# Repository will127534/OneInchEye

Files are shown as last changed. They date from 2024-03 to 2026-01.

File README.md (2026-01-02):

# OneInchEye: OpenSource IMX283 Camera Board for Raspberry Pi


### Update on 2024/03/24
This project is also compatiable with RPI5, the quickstart guide has been updated.  

## Introduction
Welcome to the **OneInchEye** project, an open-source camera board designed for Raspberry Pi Compute Module 4 boards using the IMX283 one-inch sensor. This project aims to provide a high-quality, affordable, and accessible camera module for advanced Raspberry Pi projects. The board is designed using KiCad v6, a popular open-source electronics design automation (EDA) software.

OneInchEye captures stunning high-resolution images and videos with improved low-light performance and dynamic range. It's perfect for photography enthusiasts, developers, and makers who want to level up their Raspberry Pi projects with a powerful camera. The board also features a TMP117 temperature sensor for accurate temperature readings.

**Please note that the OneInchEye is not compatible with most Raspberry Pi boards because it requires 22-pin FPC connector with 4-lane MIPI-CSI interface. Ensure compatibility with your specific board before proceeding.**

## Features
* 1-inch IMX283 sensor
* **Open-source hardware and software**
* Integrated TMP117 temperature sensor
* Integrated 6-axis IMU ICM42688-P
* Compatible with Raspberry Pi Compute Module 4 boards with a 22-pin FPC connector and 4-lane MIPI-CSI (same pinout as Raspberry Pi Compute Module 4 IO Board)

## Support
For questions, issues, or suggestions, please open an issue in the [GitHub repository](https://github.com/will127534/OneInchEye/issues)  
Also see [Quick Start Guide](https://github.com/will127534/OneInchEye/wiki/OneInchEye-Quick-Start-Guide)

## MISC stuff  
1. Blog post(?) here: https://will127534.github.io/OneInchEye/
1. I know the decoupling capacitors in sch are a mess.....  
2. IMU is hook up at the 1.8V LDO, but that LDO is controlled by CAM_GPIO (or think as a enable pin for the camera module), so it will function only when the camera is active.
3. IMU's FSYNC is conencted to VSYNC output from the sensor for measurements/frame alignment 
4. Temperature sensor is connected to 3.3V FPC input
5. There is no clock sync function for the CMOS sensor, so the XVS and XHS are output only.  
6. QWIIC is mainly for hooking up to other I2C devices so you don't have to connect yet another cable if you add additional I2C sensor to the board. But it also serves as I2C debug port to hook up external logic analyzer.  
7. This board is actually quite easy to assemble, if you want to build board yourself, you can use JLCPCB to do the PCBA on component side and do the CMOS side with low temperature soldering paste yourself if you can source the CMOS sensor. The JLCPCB BOM and Position list is also provided.
8. Limited quantity on Tindle: https://www.tindie.com/products/will123321/oneincheye/

## License
This project is released under the MIT License.



Thanks to ChatGPT helping me generating most of the Readme, see if you can spot which section I typed.

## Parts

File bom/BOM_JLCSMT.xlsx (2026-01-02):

Comment | Designator | Footprint | JLCPCB Part #（optional）
100nF | C7,C36,C40,C22,C39,C15,C24,C12,C10,C31,C30,C4,C42 | C_0402_1005Metric | C307331
KCZ1210AH900HRTD25 | FL1,FL4,FL5,FL2,FL3 | DLP11SA350HL2B | C90762
2.2uF | C44 | C_0402_1005Metric | C12530
22uF | C37 | C_0603_1608Metric | C59461
1uF | C14,C27,C9,C21,C16,C17,C1,C45,C3,C23,C11,C35,C29,C20,C19,C6 | C_0402_1005Metric | C52923
1000pF | C8,C2,C5 | C_0402_1005Metric | C1523
10nF | C43,C46 | C_0402_1005Metric | C15195
Conn_01x22_Shielded | J1 | TF3822S05SV830 | C6552695
BLM15PX800SN1D | FB4 | L_0402_1005Metric | C160978
10K | R7,R1,R6,R4,R9,R5 | R_0402_1005Metric | C25744
1.15K | R11 | R_0402_1005Metric | C477191
10uF | C34,C47 | C_0603_1608Metric | C2959727
4.7uF | C38,C18,C32,C28,C13,C33,C25 | C_0603_1608Metric | C19666
LP5907MFX-1.8 | U1 | SOT-23-5 | C92498
TPS7A90 | U2 | Texas_S-PDSO-N10_EP1.2x2mm | C840111
3.01K | R10 | R_0402_1005Metric | C304603
ICM-42688-P | U9 | IIM42352 | C1850418
Conn_Coaxial | J4,J3 | U.FL_Hirose_U.FL-R-SMT-1_Vertical | C5137195
TCA9406DC | U7 | TCA9406DCUR | C840107
BLM18KG102SN1D | FB2,FB3,FB1 | L_0603_1608Metric | C160982
22R | R8 | R_0402_1005Metric | C25092
DFE201210U-2R2M=P2 | L1 | L_0805_2012Metric | C2049745
NFM18CC101R1C3D | C26 | NFM18CC101R1C3D | C111493
ECS-2520S18-240-FN-TR | U5 | Oscillator_SMD_Abracon_ASDMB-4Pin_2.5x2.0mm | C2842194
AP3418KTR-G1 | U6 | SOT-23-5 | C500769
TMP117AIDRVR | U4 | TMP117AIDRVR | C699536
Conn_01x04_Shielded | J2 | JST_SH_BM04B-SRSS-TB_1x04-1MP_P1.00mm_Vertical | C160390

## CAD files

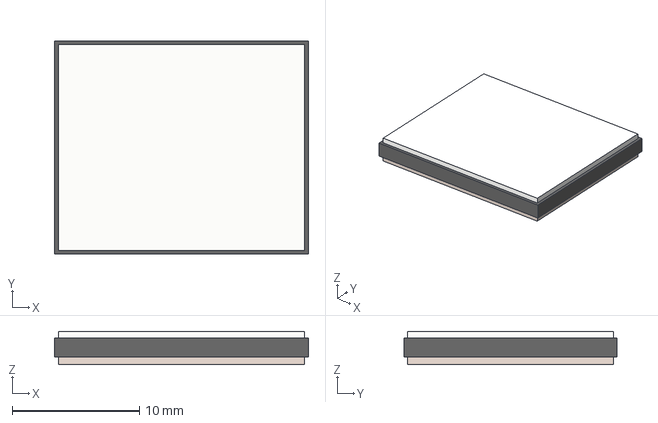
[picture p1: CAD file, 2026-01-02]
3D/IMX283.step
20.0 x 16.8 x 2.62 mm

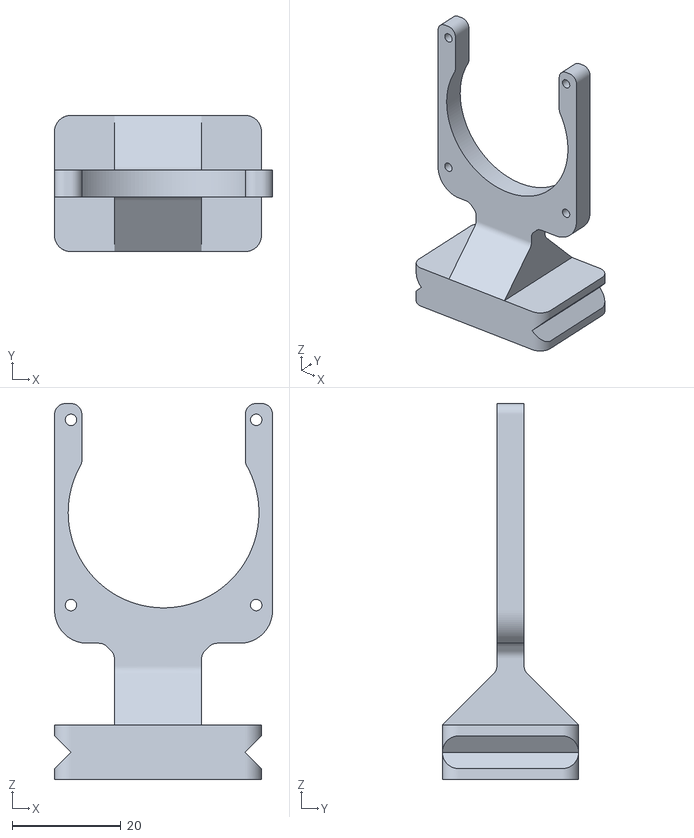
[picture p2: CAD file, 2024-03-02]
3D/QuickReleaseMount.stl
40.0 x 25.0 x 69.0

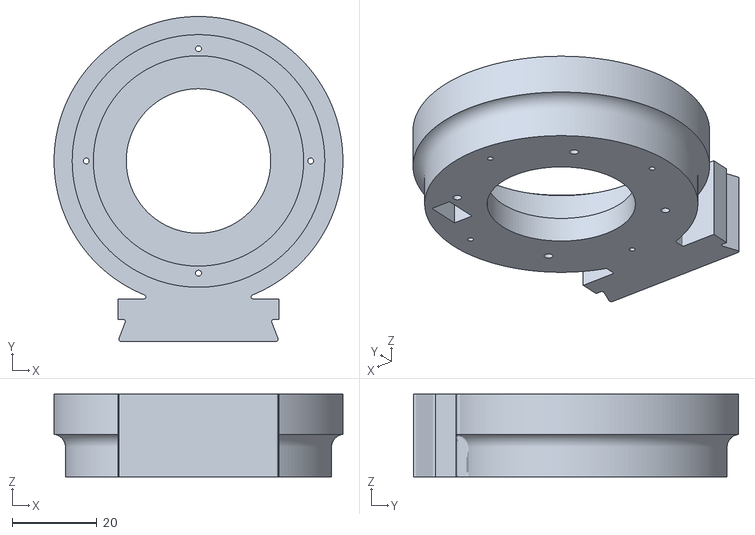
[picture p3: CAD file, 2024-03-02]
3D/PassiveEmount.stl
68.0 x 76.5 x 19.5

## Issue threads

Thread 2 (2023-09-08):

DSO Astrophotography

bebon901, 2023-09-08:
Hi,
I recently came across your sensor, and I've always been a bit of a tinkerer with Raspberry Pi's and astrophotography. I was wondering, how do you think this'd perform on a telescope?
I know what I'm doing with a proper camera, and I used the HQ Camera before but gave up since it's not big enough. Is there good driver control for Analogue gain, shutter speed etc?
What's the low light performance like in comparison to the HQ Camera?
Cheers,
Ben

bebon901, 2023-09-08:
Actually can see there's AG support!

will127534, 2023-09-11:
Yeap, there is auto gain, shutter speed and gain control.
Fun fact:
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

I'm also using it on my telescope too, though I've only tried it for solar observation. The other one will be allsky camera.
Haven't got the chance to do a proper low light performance comparison though.

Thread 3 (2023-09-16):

Sourcing the image sensor?

tlalexander, 2023-09-16:
Hello! I am not seeing any source online for the sensor. Maybe I am just missing it. Do you have any suggestions?

will127534, 2023-09-17:
I haven't tried to find it on Aliexpress, but I think you might find one or two reseller there.

matescb, 2023-10-17:
I found some on Alibaba but didn't try
https://www.alibaba.com/product-detail/-100-Brand-New-Original-IMX283EQJ_1600673386520.html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

tlalexander, 2023-10-17:
Thank you! I sent an inquiry.

tlalexander, 2023-10-17:
Okay those are $65 each, with $30 DHL shipping. I will look more at getting these base boards made, and consider building some.

tlalexander, 2023-10-24:
Oh that’s not the real price. The listing I found also said $1 but when you contact the vendor they are $65.

amits26, 2023-12-26:
@will127534 how did you managed to solder Sony IMX283 on your PCB ? how difficult it was ?

bob454522, 2024-01-15:
Im also having issues find the sensor (ie sony IMX 585), without buying an entire camera that is.
where do you all buy it from? (im in usa)  thanks

hyperphonic0, 2024-01-18:
@bob454522:

Try here: https://www.aliexpress.com/item/1005006320816093.html

Riner06, 2024-10-06:
@will127534 @tlalexander @matescb @DomML @bob454522 Do anybody know if the imx283EQJ sensor work for the oneincheye pcb? And as I understand it doesn't shoot color, is that correct? Kind regards aspiring engineer(:

will127534, 2025-02-05:
@Riner06 It is still color sensor and yes it will work on this board.

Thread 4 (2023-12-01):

Pi 5 Drivers

SamM-Springbok, 2023-12-01:
I have one of the OneInchEyes from the initial batch, but have not had a potentially compatible device until the Pi 5.

For the StarlightEye it looks like a driver for the Pi 5 is in development.
https://github.com/will127534/StarlightEye/issues/2

Does a similar driver need to be made for the IMX294? Or should the current driver and instructions work fine?

will127534, 2023-12-05:
Yeap, I'm still working on it.....

I've tested OneInchEye, StarlightEye and IMX294 board all shows some issues on RPI5, I'm still figuring out what is happening.

will127534, 2024-01-21:
[imx283-v4l2-driver](https://github.com/will127534/imx283-v4l2-driver)

I've updated the IMX283 driver here.

Isonoglu, 2024-03-05:
I am experiencing a similar issue as SamM-Springbok described initially regarding compatibility with the Pi 5. Have you resolved the problems with the OneInchEye on the RPi 5, or are there still issues to be aware of? Additionally, is the updated IMX283 driver applicable to this situation?

After completing the steps in the readme from this link: https://github.com/will127534/imx283-v4l2-driver how can I verify that my camera system works on RPi 5?

I went through Quick-Start-Guide  https://github.com/will127534/OneInchEye/wiki/OneInchEye-Quick-Start-Guide but when tried to execute the last command: rpicam-still -r -o test.jpg -f -t 0 an ERROR pops up stating: "rpicam-aps currently only supports the Raspberry Pi platforms..."

Are there are any major differences between OneInchEye V1.4 and OneInchEye V1.3? I have both, but don't have a CM4 board to test them.

Have you any information about the power consumption of the OneInchEye camera? I'm also trying to connect the OneInchEye to the FPGA with a 4-lane connector, but have some problems. Could the power consumption of the camera be the case?

will127534, 2024-03-06:
Hi @Isonoglu

Yes, I have resolve the issues, I've actually updated the drivers and guide last week, now it should work if you follow the setup guide (I've also verified it is working on my RPI5).

For the error, have you restart your RPI5? I also got that error if I did not reboot after recompiling rpicam-apps, but after a reboot the message will goes away.

There is no difference in terms of the Sensor between v1.3 and v1.4, so they should be the same.

For the power consumption, I don't have that handy but I will say it shouldn't be a huge issue (I've run it with a 50cm length FPC cable), if you have other board that is not RPI manufactured, can you check if the enable pin on the FPC has asserted?  There is a enable signal on the FPC that will power up/down the sensor. Enable pin is also one of the difference between V1.3 and V1.4, on V1.4 you can solder the enable pin jumper to ignore that enable pin or default to pulled-high.

will127534, 2024-03-09:
@Isonoglu Can you try re-install the v4l2 driver? I noticed that during the libcamera compiling, some package installed will trigger update-initramfs which then will caused dkms driver to disappear.

Isonoglu, 2024-03-10:
Hello, I just want to inform you that I went through the procedure in the Start Guide again and tried a different camera port, which resulted in success. You just need to change this line: 'sudo nano /boot/config.txt', because the config file isn't on that path. But everything else is straightforward."

will127534, 2024-03-11:
@Isonoglu Thanks for the confirmation!
Also note that you can add `,cam0 ` to the dtoverlay to move the port to Cam 0 (By default it is using Cam 1 because historical reasons: RPI default uses cam0 interface because that is the only one with 4-lane MIPI).

I'll update the guide as your suggestion and also some ports indicator!

Thanks a lot !

will127534, 2024-03-24:
Updated the quick start guide

Closed 2024-03-24.

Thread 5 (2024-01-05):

OneInchEye Camera Interface Board for CM4

amits26, 2024-01-05:
Hi,

I am really interested to build oneincheye camera for my telescope and I working on sourcing PCB from JLCPCB as oneincheye is out of stock. Only concern I am having now is not able to find any baseboard for CM4 with 22Pin CSI interface. I don't want to go with CM4 I/O board which is bulky and looks to be only option for 22Pin CSI connector. There are some base boards with 15pin CSI connectors like PiCam Module for Raspberry Pi Compute Module 4 but again with 15Pin CSI connector. I don't think 15pin is right choice looking at your design. is there any other way to connect oneincheye camera module to CM4 without making it bulky ?

Thanking in advance.

Amit

will127534, 2024-01-06:
Yeah that is also the reason why I've build my own CM4 camera board with 22pin 4-lane MIPI connector.
No way other then building yourself one because it is rare for anyone building a CM4 baseboard for almost non existent camera modules.
Another easier option will be using RPI5 directly, which I've been working on updating the driver. Moreover you get the bonus of having PCIe 3.0 x1 connector for faster drive speed if you are planning for planetary Imaging.

Closed 2024-01-06.

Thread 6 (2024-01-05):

Upstream the IMX283 and IMX585

phodina, 2024-01-05:
Hi @will127534 ,
thanks for cool project! I intend to use the sensor as well :-)

If you want I can upstream the sensors into the Kicad library so they could be used also by other projects.

I made some modifications to the schematics and footprint. More will be definitely needed for the symbol.

In the end I can open a pull request here with the modifications so that this project will use the symbol and footprint from the official Kicad libraries.

https://gitlab.com/phodina/kicad-footprints/-/commit/1206c688dd991517be1584b2a080f78f604ae323
https://gitlab.com/phodina/kicad-symbols/-/commit/510736715b263a41a45da1ea4ede2d00370c0934

Also could you share a link for the datasheet for the sensors? It's needed for the review process

amits26, 2024-01-05:
@phodina how you are planning to use sensor board with CM4 ? other than CM4 official IO board there is no other breakout board which exposes 4 lane MIPI CSI interface for CM4. Also drivers won't support RPI5

will127534, 2024-01-06:
Thank you!
Feel free to do modifications and upsteam!

The only issue is that... Even though I did not sign the NDAs to get the datasheet (i.e I've gathered from the interenet), I'm a little bit hesitant to share publicly.

phodina, 2024-01-06:
> @phodina how you are planning to use sensor board with CM4 ? other than CM4 official IO board there is no other breakout board which exposes 4 lane MIPI CSI interface for CM4. Also drivers won't support RPI5

Well there are other boards that expose the 4 lane MIPI CSI interface e.g. the Quartz64 Model A

https://wiki.pine64.org/wiki/Quartz64 (under Expansion Ports)
> CSI - CMOS Camera Interface, 4 lanes MiPi up to 8 mega pixel on model A, 2 lanes MiPi up to 5 mega pixel on model B

I also work with the sensors in my day job and there are platforms such as HyIMAGE Pro V5U R2 IMAGE Toolkit that are for calibrating/testing of the image sensors.

https://cn.hyvision.co.kr/shop_view/?idx=12/#prod_detail_body

phodina, 2024-01-06:
> Thank you! Feel free to do modifications and upsteam!
>
> The only issue is that... Even though I did not sign the NDAs to get the datasheet (i.e I've gathered from the interenet), I'm a little bit hesitant to share publicly.

Sure. As with any other image sensor it's always difficult to work with the manufacturers as they keep the lid on the specification and require to buy large volume just to give away some datasheets under NDA.

However, would it be possible to release at least the specification for the package (footprint) and the pinout?

Without that it's hard to check the symbol and footprint.

There are other products with this sensor so might be possible to ask them if they would share the datasheet:

https://www.arducam.com/product/arducam-20mp-imx283-camera-module-with-m12-mount-lens-and-adapter-board-for-depthai/

https://www.framos.com/en/products/fsm-imx585-sensor-module-26378

phodina, 2024-01-08:
FIY @will127534

https://gitlab.com/kicad/libraries/kicad-footprints/-/merge_requests/3403
https://gitlab.com/kicad/libraries/kicad-symbols/-/merge_requests/4186

will127534, 2025-02-05:
Close for old issue.

Closed 2025-02-05.

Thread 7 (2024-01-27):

v1.4, EQJ vs. CQJ, JLCPCB ordering

theplanekid, 2024-01-27:
I keep missing the Tindie restocks, so I’m going to bite the bullet and build some boards myself.
@will127534 would you consider updating the files to v1.4 as you’re selling on Tindie? Completely understand if not.
What’s the correct sensor to use, IMX283EQJ or CQJ? What’s the difference? Can’t seem to find an answer myself; here and files say EQJ, Tindie listing says CQJ, so I’m a bit confused.
Also are there any considerations for ordering the PCB other than the filled vias? Anything to keep in mind when soldering the sensor itself?

Thanks!

will127534, 2024-01-27:
Yeap, building one yourself will be the fastest way to get one haha. Highly recommend if you have soldered/build SMD PCBs before. Also at this sensor size you would want to customized it in some degree too.

I'll upload the V1.4 later, yes - Actually I'll close this issue once I get it uploaded.
As for IMX283EQJ or CQJ... Honestly I don't know what is the difference either, but I use IMX283EQJ-C, I'll update the Tindle link later.

Nothing special about the PCBs other then filled vias, so I think that's all you need to take care of when ordering. For soldering the sensor, if you see condensing in the sensor when you cool down the board after soldering, don't worry it will go away.
Typically I use heatgun and heat it from the bottom of the board (Components side) or a IR pre-heater, but I have used heatgun from the top without problems (i.e cracking the glass) with low temperature soldering paste.

theplanekid, 2024-01-27:
I’ll start sourcing the sensors while I wait for v1.4, and thanks for the info!
Oh also, what size IR filters should I be getting?

will127534, 2024-01-27:
20mm x 16.8mm

theplanekid, 2024-01-27:
Thanks again!

will127534, 2024-02-17:
Updated PCB files to V1.4

Closed 2024-02-17.

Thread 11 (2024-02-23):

compatible cm4 adapter

almowery, 2024-02-23:
I can't wait to use my one inch eye.  I have looked at all the cm4 adapter boards and only one says that it has a camera CSI-2 4 lane interface.  That one is Ochin.  This is a minimal board with no HDMI support.  I would prefer to have one with the HDMI port.  Can you recommend one?  I have  a PI 5 and that would be better.  I was not able to figure out how to compile the kernel.  Thanks.

will127534, 2024-03-06:
It should work with RPI5 now : D

Closed 2024-03-06.

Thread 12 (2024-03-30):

rpicam-jpeg failed to capture  "Camera frontend has timed out!"

will127534, 2024-03-30:
Camera failed to capture jpeg using `rpicam-jpeg --cam 0 -o default.jpg`
The issue is related to the camera mode transition between the preview default SRGGB12_CSI2P,2784x1828 to the still pipeline's SRGGB12_CSI2P,5568x3664/0, for some reason the cmos sensor is not sending a complete frame after the transition that causes the camera frontend to timeout.

A workaround is to ask rpicam-jpeg to use the same mode for preview:
` rpicam-jpeg --cam 0 --viewfinder-mode 5568:3664:12:P --mode 5568:3664:12:P -o default.jpg`

Using the logic analyzer on the XVS and XHS pin shows that after the transition, hblank is still sending signals but no vblank were asserted. From the duration it looks like the sensor is stuck at the same hblank interval as the 2.7K state (~4.8us) and hasn't been updated to the correct hblank of ~10us.

Interestingly no other mode is impacted, only mode 0 (SRGGB12_CSI2P,5568x3664), if we use ` rpicam-jpeg --cam 0 --mode 5568:3664:10:P -o default.jpg` the camera app works just fine.

will127534, 2024-03-30:
Judging from the I2C write traces, the transition to mode 0 is missing the IMX283_REG_HMAX(0x3036) write.

will127534, 2024-03-30:
`rpicam-jpeg --cam 0 --mode 5568:3664:10:P -o default.jpg`
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

`rpicam-jpeg --cam 0 --mode 5568:3664:12:P -o default.jpg`
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

will127534, 2024-03-30:
Ok I think there must be some issue with the logic analyzer, or that causes the I2C low level floor being to high for the Mosfet level shifter, using the new V1.4 board I can see the HSYNC changes.

But also found out that the power management doesn't seems to be working, as the enable pin is keep at asserted through out the test.

Comparing with the imx477.c driver I noticed that we have enable runtime PM with autosuspend:

```
	/*
	 * Enable runtime PM with autosuspend. As the device has been powered
	 * manually, mark it as active, and increase the usage count without
	 * resuming the device.
	 */
	pm_runtime_set_active(dev);
	pm_runtime_get_noresume(dev);
	pm_runtime_enable(dev);
	pm_runtime_set_autosuspend_delay(dev, 1000);
	pm_runtime_use_autosuspend(dev);
```

And here is the IMX477 driver
```
	pm_runtime_set_active(dev);
	pm_runtime_enable(dev);
	pm_runtime_idle(dev);
```

Changing the code to the one in IMX477 I can see the camera capture is working, and enable pins are being used.
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

@kbingham Do you know if the autosuspend is a feature on newer kernel or it should be also on Kernel v6.1 and v6.6?

will127534, 2024-03-30:
Temporary rollback the pm_autosupend in the driver for v6.6 and v6.1

kbingham, 2024-03-30:
Argh, so I've probably messed up the runtime pm :-( sorry, I'll take a look.

will127534, 2024-03-30:
No worries! I'm just ping you here so you can check the upstream driver.

kbingham, 2024-04-02:
@uajain could you check the runtime pm on the latest imx283 please?

kbingham, 2024-04-04:
@uajain could you check the runtime pm on the latest imx283 please?

will127534, 2024-04-04:
The issue looks like the power management isn't working as intended (It isn't powering down the sensor when unused).

uajain, 2024-04-04:
> The issue looks like the power management isn't working as intended (It isn't powering down the sensor when unused).

Oh, then it is probably my fault. I will try to look through the code and identify what explains such behaviour.

> Can you probe the enable pin on the camera to see if mainline driver will power down the camera?

This seems I should have a logic analyser on my end (which I don't). Is there any other method @kbingham ?

kbingham, 2024-04-04:
@uajain you can use i2c-detect to see if it's powered up I think. Or rwmem etc.

uajain, 2024-04-04:
@will127534 Can you tell when driver variant you are using (is the some versoin of the mainline driver that was posted) ? Also the device tree?

Note that we recently changed the handling of the reset pin, so I have to check if that's the one causing issues. I am keeping to infer the 'reset' and 'enable' pin - are they the same or different etc, but yes we did have changes there - so I am suspecting that didn't go right.

uajain, 2024-04-04:
> @will127534 Can you tell when driver variant you are using (is the some versoin of the mainline driver that was posted) ? Also the device tree?
>
> Note that we recently changed the handling of the reset pin, so I have to check if that's the one causing issues. I am keeping to infer the 'reset' and 'enable' pin - are they the same or different etc, but yes we did have changes there - so I am suspecting that didn't go right.

This was being discussed internally and we think that the reset device polarity (since we reversed it) is what causing the issue.  It is a DT issue

Can you invert the polarity in DT and check again please @will127534 with autosuspend

kbingham, 2024-04-04:
Will shouldn't be using the reset gpio pin. His camera module is connected to a raspberry pi 5 and only has the power regulator enable. It should be the same set up as yours.

uajain, 2024-04-06:
> Will shouldn't be using the reset gpio pin. His camera module is connected to a raspberry pi 5 and only has the power regulator enable. It should be the same set up as yours.

ah okay, I should be reading the pin status then (trying to read it through commandline, figuring out how) ..

How is rwmem possible to see through this? It only reads register address no?

kbingham, 2024-04-07:
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

Exactly. If you can read the registers, it's powered on. If you can't, it's powered off.

If you can read when it should be off ... Then the runtime pm is broken and isn't turning the camera off.

It's harder to read the gpio pin state on an output. But maybe there's a way to read the expected state from either libgpiod Or just check by adding prints to the power functions in imx283.c ... Lots of options...

uajain, 2024-04-10:
I can read the registers when camera is not streaming,so indeed the  pm runtime is broken

uajain, 2024-04-10:
> I can read the registers when camera is not streaming,so indeed the pm runtime is broken

Ok, fhe PM runtime is fine, it's the single stream case which is causing this symptom. In this case, (as we already know earlier - .enable_streams() wouldn't be called unless a special hack) - the .disable_streams() suffers from a similar problem. Hence no .disable_streams() is called on camera stop (and hence no, pm_runtime_put_*() calls gets executed) - so sensor is kept powered on...

I did a similar workaround on .disable_streams() to check the hypothesis, and after .disable_streams() is called by the driver- sensors gets powered-off correctly in my testing.

We need to wait a bit before this enable/disable streams issue gets fixed upstream [1]. But that is the core issue, not the pm_runtime_management part of the driver

@will127534 I am not sure which driver you have tested (custom or any version of upstream, mention if any?) - but this is what I noticed on my latest upstream IMX283 driver.

[1] : https://lore.kernel.org/linux-media/20240410-enable-streams-impro-v3-0-e5e7a5da7420@ideasonboard.com/T/#t

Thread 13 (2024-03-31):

Quick Start Guide suggestion

theplanekid, 2024-03-31:
Hello!
I’m rather inexperienced with RPi, and especially the 5, so I spent a decent part of today trying to install libcamera and the driver. I was only successful upon a fresh reflash, uninstalling rpicam-apps, and only then going through the install process.
Thus, a possible suggestion for the quick start guide; tell users to uninstall rpicam-apps before installing your forked version?
A friend who’s more experienced tells me that installing under an alias is also an option, so perhaps do that instead?
Also, some of the commands are the one-click copy thing and others aren’t, but that’s a very minor nitpick.
Once again, just suggestions.
Thanks for the cool hardware/software and the development work you’ve put in!

will127534, 2024-03-31:
I don't think you will need to uninstall rpicam-apps, because after you follow the libcamera install process, the next one is to install rpicam-apps, which should overwriting the existing one.
I did go through the quick start guide a couple of times myself but I don't think I ever need to uninstall rpicam-apps, what was the issue when you follow the guide?

I'll update the guide to pack some cmds, thanks for the advice!

theplanekid, 2024-03-31:
Hmm odd, I assumed it would overwrite but I also ran through multiple attempts of the install process, reflashing each time, and got the rpicam-apps only supports the raspberry pi platform or something along those lines.

will127534, 2024-03-31:
If you got the "rpicam-apps only supports the raspberry pi platform" error, that can actually mean the driver is not loaded correctly, check if you see the imx283 in dmesg by `dmesg | grep imx283`, you should see some message like:

```
[    3.328314] rp1-cfe 1f00110000.csi: found subdevice /axi/pcie@120000/rp1/i2c@88000/imx283@1a
[    4.265573] imx283 6-001a: Device found
[    4.265620] imx283 6-001a: Pixel Rate : 451968432
[    4.265627] imx283 6-001a: Setting default HBLANK : 81, VBLANK : 336 with PixelRate: 451968432
[    4.265644] rp1-cfe 1f00110000.csi: Using sensor imx283 6-001a for capture
```

theplanekid, 2024-04-03:
I tried on a fresh SD card and everything went through without a hitch so I don't know what I was doing wrong the first time.
Such is life. Thanks for the help!

will127534, 2024-04-03:
I think the error "only supports the raspberry pi platform" is really misleading, I have scratch my head for a while debugging that also, I'll add a debug section to the quick start guide.

will127534, 2024-08-04:
Alright - Quick start guide updated

Closed 2024-08-04.

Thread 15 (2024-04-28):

pcb problem

yassinebkr, 2024-04-28:
hello I'm trying to make the pcb from pcbway because there is some big shortages on jlcpcb and they ask me that :
Hello Dear,
Thanks for your inquiry on PCBWay, this is Lynne.
As shown in attached screenshot.
1. The spacing between IC pins in circle is smaller than 0.22mm, cannot make soldermask bridge.
Could you accept to proceed without bridge?
Highly suggested to change the soldermask color from black to green/blue/red to make out the bridges,
in order to prevent solder paste connected cause the short circuit during assembly, is that ok for you? If yes, pls advise the new color option.
Or do you prefer to retain the current design and soldermask color, put this order to our high-quality factory to make out the soldermask bridge? If yes, price and build time both will increase, kindly noted that.

2. Some vias be designed on the SMD pads, pls advise if proceed with via-in-pad process?
If yes, this service is chargeable (over $100usd) and vias are to be non-conductive epoxy filled, plated over with copper and planarized.
If not, in order to guarantee assembly quality, it's suggested you can update design, move vias away from SMD pads and attach the new gerber files by email.
Looking forward to your reply.
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
what should I reply ?
Your  work is insane btw

yassine

will127534, 2024-04-28:
1. That means the manufacture can not make the soldermask in between the pads, either you accept and take the risk of soldering short happening at those areas or you ask them to use a better PCB process that has higher cost.
2. Yes, you will need via-in-pad

Closed 2024-04-28.

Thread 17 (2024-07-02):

Rpi5 Failed to start with OneInchEye camera attached

watchever, 2024-07-02:

watchever, 2024-07-02:
I also add the JLCPCB gerber 2D viewer. Maybe a polarity issue ?
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

watchever, 2024-07-02:
Ok think I have found myself issue. The engraved on 22pins port are a mess.... Don't know why, like if Gerber files were corrupted.

will127534, 2024-07-02:
I download the gerber straight from github and upload to jlcpcb and the render is perfect:
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

I don't know why you think the gerber is corrupted, literally zip it, upload it. Also I want to stress that if you are not familiar with PCB and or electrical engineer, please look else where.

will127534, 2024-07-02:
There are multiple issues on your PCB board by the way

watchever, 2024-07-02:
Hi Will, not saying that your PCB file is corrupted. It is by comparing my PCB file with yours that I found issues. So what I mean is my PCB files were modified in unexpected way by EasyEda. I have download Kicad files in EasyEda and generate gerber files with poor rendering. Really don't know why.

watchever, 2024-07-02:
So if you find others issues in my PCB screenshot other than the wiring of the 22pins, please let me know.

watchever, 2024-07-02:
Will, I know I am not a star with PCB. I do my best to learn, but if you can give me some advices to correct my mistakes on my previous PCB order, I will be really grateful. Maybe you will be happy to know that I plan to use the OneInchEye module for an astronomy project  which already use a IMX462 module but I want to upgrade to the IMX283. Thanks in advance for your time.

watchever, 2024-07-03:
I confirm that importing the Kicad project in EasyEda generate erroneous wiring...
I'd rather state it for other users, than just saying like @will127534 that I should look elsewhere (useless reply).

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

Closed 2024-07-02.

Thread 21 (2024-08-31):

IMX283 datasheet

new299, 2024-08-31:
Hi,

I was wondering if you might know where I could find the IMX283 data sheet? I have a board with an IMX283 on it which I want to try and adapt to use with the Pi but there are a few things I'm unclear on. Sorry for creating an issue, but couldn't find another way to contact you. My email is new@sgenomics.org.

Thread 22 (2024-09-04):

Issue of striped lines appearing in photos.

kitcheng, 2024-09-04:
Thank you very much to the developers; this is an amazing project.

When I take photos at the highest resolution (5568x3664), there are striped lines at the edges of the photos. Is this a known issue that is considered normal, or is it abnormal and potentially related to factors such as software or cable connections?

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

will127534, 2024-09-04:
Yes it is normal, those are extra pixels/black pixels at the edge that can be cropped out.
Specifically, the issue is that for some reason I can not cropped out those at the driver level, if I set the resolution to the supposedly correct sizes on RPI5 it will causes stride unmatching.

kitcheng, 2024-09-05:
Alright, I understand. I'll crop it at the application layer. Thanks again.

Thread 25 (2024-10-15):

What sensors are supported here other than IMX283EQJ-C?

maifeeulasad, 2024-10-15:
First I want to say this is one awesome project.

But I couldn't find any section where it mentions what other sensors it connect to other than `IMX283EQJ-C`. Can you please share this data with us? And one more thing, is `IMX283EQJ-C` the correct sensor?

will127534, 2025-02-05:
Both IMX283 variant should work

Honestly I don't know what is the difference between IMX283EQJ vs IMX283CQJ

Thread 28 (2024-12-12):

Feature request: mounting holes

jockm, 2024-12-12:
It would be nice to have some mounting holes on the PCB.  Obviously there isn't any room currently, but I could imaging expanding the PCB out on two sides to have breakaway "wings" that had mounting holes.

Closed 2025-02-05.

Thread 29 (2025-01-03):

Is there a 3D model of module itself?

jockm, 2025-01-03:
Just curious if you have a 3D model of the module itself, or the lens mount.  It would save a step when modeling a case that goes around the module.

will127534, 2025-02-05:
I don't have the full 3D model for the camera module PCB (without the camera sensor 3D), and it can be generated via KiCad.

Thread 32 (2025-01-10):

Inquiry About Removing TMP117 and ICM42688-P for Static Image Applications

kitcheng, 2025-01-10:
This is an amazing design, and I sincerely appreciate your sharing it.

I noticed that the PCB includes an integrated TMP117 temperature sensor and a 6-axis IMU ICM42688-P. However, I plan to use it solely for capturing static images and won’t require the temperature or IMU data.

Could you please advise how to remove them? Would it be sufficient to simply not solder these components? Thank you!

will127534, 2025-01-10:
You can skip them by no soldering them directly

Closed 2025-01-10.

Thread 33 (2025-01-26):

What is the c-mount adapter that is sold with the sensor on tindie

jockm, 2025-01-26:
On tindie the OneInchEye comes with a metal c-mount adapter that screws onto the sensor board. Is this an off the self component? Something you designed? Etc?

If off the shelf could you say where it comes from? If it is something you designed, is it a design you can share?

will127534, 2025-02-05:
Off the shelf parts, you should be able to find them on Aliexpress.
https://item.taobao.com/item.htm?id=757382026946

jockm, 2025-02-05:
Thank you very much!

Closed 2025-02-05.

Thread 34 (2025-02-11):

About the Tuning File

kitcheng, 2025-02-11:
Hello, first of all, thank you for your efforts—this is a great project.

I noticed that you have provided a tuning file, but I feel that the auto white balance tends to make the colors appear too red. I would like to know how this tuning file was measured and obtained. Do you have any suggestions or insights to share?

will127534, 2025-02-12:
Quick question just to clarify, do you have IR cut filter installed?

kitcheng, 2025-02-12:
> Quick question just to clarify, do you have IR cut filter installed?

Yes, I added an 850nm IR filter to the lens.

will127534, 2025-02-12:
notes that recalibration (i.e generate tuning files for your optical system) won't help the color I think because 650nm~850nm is in IR range that the sensor will pickup.

kitcheng, 2025-02-13:
> That might be the reason, I'm using 400nm to 650nm pass filter
>
> 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

Okay, thank you very much! I’ll try changing the filter.

Closed 2025-02-13.

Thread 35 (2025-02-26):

Actual max frame rate for each readout Mode

ingenico-zanetti, 2025-02-26:
Hello,

from both https://www.sony-semicon.com/files/62/pdf/p-13_IMX283CQJ_Flyer.pdf and the comment in your code (imx283.c, in static const struct imx283_mode supported_modes_10bit[]), the maximum frame rate for MODE 1A should be just above 30 fps.

Yet, when using libcamera-vid, the available mode have a much lower max frame rate:

    SRGGB10_CSI2P,5568x3094/21.3074 - Score: 0
    SRGGB10_CSI2P,5568x3664/17.9931 - Score: 4996.28
    SRGGB12_CSI2P,2784x1828/35.5454 - Score: 9929.91
    SRGGB12_CSI2P,5568x3664/17.9931 - Score: 5996.28

This does work up to 20 fps (excerpt from syslog):

[ 6434.987915] rp1-cfe 1f00128000.csi: Using a link rate of 1440 Mbps
[ 6435.422649] imx283 11-001a: Using clk freq 24 MHz
[ 6435.449600] imx283 11-001a: Mode: Size 5568 x 3094
[ 6435.449602] imx283 11-001a: Analogue Crop (in the mode) 40,393 5472x3078

Above this frame rate (30 fps), the 2784x1828 12bpp mode is selected (by application ? libcamera ? driver ?)

[ 7547.113476] rp1-cfe 1f00128000.csi: Using a link rate of 1440 Mbps
[ 7547.523729] imx283 11-001a: Using clk freq 24 MHz
[ 7547.550688] imx283 11-001a: Mode: Size 2784 x 1828
[ 7547.550691] imx283 11-001a: Analogue Crop (in the mode) 40,108 5472x3648

Has it something to do with the clock being only 24MHz and not the maximum 27MHz stated in the datasheet ?
Or a limitation on maximum pixel throughput on Pi 5 side ?
Is it be possible to have 4K at 30 fps with the IMX283 on the Raspberry Pi 5 ?

will127534, 2025-02-26:
https://www.willwhang.dev/Solar-eclipse-2024/#overclocking-the-rp1-for-enhanced-pisp-performance

ingenico-zanetti, 2025-02-27:
Wonderful: it is now running at 30 fps in 5568 x 3094 10 bpp !
Thanks a lot.

Closed 2025-02-26.

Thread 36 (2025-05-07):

Driver installation issues

eva-00100, 2025-05-07:
I made the board according to the requirements, and now there is such an error after installing the driver I'm not sure if it's a problem with the board or a problem with the driver installation Please help me This problem has been bothering me for many days.

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

eva-00100, 2025-05-07:
This is a screenshot of the driver when it was installed.
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

will127534, 2025-05-07:
driver install looks good, so it is the problem of your board that the driver can not read the sensor

eva-00100, 2025-05-07:
Thank you, I will try to solve this problem

eva-00100, 2025-05-08:
I am not very familiar with hardware, and the board is outsourced to a factory, so I would like to ask if there is a high probability of sensor damage😂😂

will127534, 2025-05-08:
I can't magically diagnose your hardware virtually, so I don't know.
What I noticed however, is your current driver is loaded for CAM0, make sure you have the camera module connects to the right connector.

eva-00100, 2025-05-08:
Thank you very much. I will continue to try to solve the problem❤️😃

eva-00100, 2025-05-08:
Maybe the problem was caused by me using the opposite FPC cable

eva-00100, 2025-05-08:
I reversed the FPC cables and it became like this.
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

eva-00100, 2025-05-08:
The 3.3v on the board is there, but the 1.8v and 2.9v my ammeter shows none.

will127534, 2025-05-08:
Can you pose a few (good) images of your board along with a few more showing how are you connecting the camera to RPI

eva-00100, 2025-05-08:
Of course, I'm sorry for replying late
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

eva-00100, 2025-05-08:
I understand what you mean, I downloaded the package on github, unzipped it, opened it with kicad, and then packaged it into a zip pcb made with JLCEDA

will127534, 2025-05-08:
I'm noticing a lot of difference between the board and what it should looks like, you will need to double check with JLCEDA on the correctness after converting that. In general, converting the PCB file format is like converting Python code to C code, while Gerber is the compiled output.

i.e if you compare the PCB image side by side with KiCad and converted result on JLCEDA, there should be quite a lot of differences and I think that is why.

eva-00100, 2025-05-08:
I understand, thank you very much for your help. I will continue to study and research this knowledge. Thank you for your help❤️❤️😃😃

eva-00100, 2025-05-20:
This time I made the circuit board according to the requirements and successfully recognized it on the Raspberry Pi, but I encountered the problem shown in the picture. I replaced the ribbon cable several times, but the error still occurred.

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

will127534, 2025-05-20:
No frame received = connection issue on the CSI-2 lanes. I2C device found = Power and I2C communication are good.

Check the CSI-2 Filter origination and the connection on the FPC connector.

eva-00100, 2025-05-20:
Thank you very much for your help, I found that the welding of FL5 when I welded the virtual soldering problem solved perfectly Thank you again for your help❤️😀😀

Closed 2025-05-07.

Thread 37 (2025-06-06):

two camera problem

almowery, 2025-06-06:
Will I have had great success with your sensor imx283. I wonder if you know of this problem with still pictures with raspberry pi.

starting with rpi 5 10 sec exposures I found on the web this script would work the best removing the one frame drop issue.  first exposure time 20sec ,second exposure 10 seconds.  The first exposure takes 2x the --shutter time.

rpicam-still --output test.jpg --timeout 1 --analoggain 1 --awbgains 2.51,2.1 --saturation 1 --contrast 1 --sharpness 1
 --brightness 0 --quality 100 --nopreview --width 4056 --height 3040 --shutter 10000000 --autofocus-mode manual --immediate
--camera 0/1

 The one frame drop would cause the time to get a 10sec exposure to increase to 20sec.  The typical camera using one frame
 to adjust then one frame to capture.  with the oneincheye the first exposure takes 20sec then the second back to 10sec.

 I have been trying to get two cameras to work together and I always had trouble getting a second camera through Tindie, so I
 bought two from arducam.  Their connector is reversed and they seemed to work fine except I could never get them to drop
 exposure time down to 10sec.  even starts first frame at 40sec.  then next frame is 20sec.

 I dont see why the two boards could behave so different.  Here is a table of operation using arducam(ard) and William(will)
 (port, port,cam0 exposure first seconds, cam0 exposure second seconds, cam1 exposure first seconds, cam1 exposure second seconds)

 Cam0 	Cam1	cam0 first	cam0 second	cam1 first	cam1 second
 ard			        40			20
		ard								40			20
		will		        					60			60
will			        20    		10
will	ard		        40     		20			20			10

It's weird by itself will's cam does good 20/10.  with two cameras will's cam does bad 40/20 and ard camera does good 20/10.
I have considered making a helperfile(compile in libcamera)  for imx283.  I read that through this one can stop the one frame drop, first change in exposure.
Do you have any suggestions for the difference between arducam and Will's camera and why the inconsistency with which camera has 20/10 first exp/second exp.
I thought it was the csi-4 lane bus issue, but it has to be something to do with enumeration of each camera and what "helper" or "default" file is selected.
40sec would indicate 3 frames dropped and one taken.  I don't even know of a camera that drops three frames.  Any ideas.  Have you seen this?

almowery, 2025-06-06:
first --camera 0 is Will camera
second --camera 1 is Arducam

notice when the camera starts line 8-21 both cameras are activated i2c@80000 and i2c@88000

jackblack@raspberrypi:~/star_recognizer3 $ rpicam-still -o test_data/testR.raw --timeout 1 --tuning-file imx283.json --analoggain 1 --awbgains 1.0,3.5 --saturation 1 --contrast 1 --sharpness 1 --brightness 0  --nopreview --autofocus-mode manual --immediate --gain 1 --shutter 10000000  --camera 0 -v
[1:17:47.363857394] [2523]  INFO Camera camera_manager.cpp:284 libcamera v0.0.0+4579-80845ad5
[1:17:47.365970068] [2524]  INFO RPI pisp.cpp:662 libpisp version v1.0.4 6e3a53d137f4 07-03-2024 (09:04:18)
[1:17:47.367589833] [2524]  WARN CameraSensorProperties camera_sensor_properties.cpp:274 No static properties available for 'imx283'
[1:17:47.367611685] [2524]  WARN CameraSensorProperties camera_sensor_properties.cpp:276 Please consider updating the camera sensor properties database
[1:17:47.374573967] [2524]  WARN RPiAlsc alsc.cpp:170 no luminance table - assume unity everywhere
[1:17:47.376080491] [2524]  INFO RPI pisp.cpp:1121 Registered camera /base/axi/pcie@120000/rp1/i2c@80000/imx283@1a to CFE device /dev/media2 and ISP device /dev/media4 using PiSP variant BCM2712_C0
[1:17:47.376136547] [2524]  INFO RPI pipeline_base.cpp:1144 Using configuration file '/usr/share/libcamera/pipeline/rpi/pisp/rpi_apps.yaml'
[1:17:47.376292547] [2524]  INFO RPI pisp.cpp:662 libpisp version v1.0.4 6e3a53d137f4 07-03-2024 (09:04:18)
[1:17:47.377391403] [2524]  WARN CameraSensorProperties camera_sensor_properties.cpp:274 No static properties available for 'imx283'
[1:17:47.377424199] [2524]  WARN CameraSensorProperties camera_sensor_properties.cpp:276 Please consider updating the camera sensor properties database
[1:17:47.383102996] [2524]  WARN RPiAlsc alsc.cpp:170 no luminance table - assume unity everywhere
[1:17:47.384442408] [2524]  INFO RPI pisp.cpp:1121 Registered camera /base/axi/pcie@120000/rp1/i2c@88000/imx283@1a to CFE device /dev/media1 and ISP device /dev/media3 using PiSP variant BCM2712_C0
[1:17:47.384487445] [2524]  INFO RPI pipeline_base.cpp:1144 Using configuration file '/usr/share/libcamera/pipeline/rpi/pisp/rpi_apps.yaml'
Options:
    verbose: 2
    info_text:
    timeout: 1ms
    width: 0
    height: 0
    output: test_data/testR.raw
    post_process_file:
    preview: none
    qt-preview: 0
    transform: identity
    roi: all
    shutter: 10000000us
    gain: 1
    metering: centre
    exposure: normal
    ev: 0
    awb: auto
    awb gains: red 1 blue 3.5
    flush: false
    wrap: 0
    brightness: 0
    contrast: 1
    saturation: 1
    sharpness: 1
    framerate: 30
    denoise: auto
    viewfinder-width: 0
    viewfinder-height: 0
    tuning-file: imx283.json
    lores-width: 0
    lores-height: 0
    autofocus-mode: manual
    autofocus-range: normal
    autofocus-speed: normal
    autofocus-window: all
    hdr: off
    mode: unspecified
    viewfinder-mode: unspecified
    metadata:
    metadata-format: json
    encoding: jpg
    quality: 93
    raw: 0
    restart: 0
    timelapse: 0ms
    framestart: 0
    datetime: 0
    timestamp: 0
    keypress: 0
    signal: 0
    thumbnail width: 320
    thumbnail height: 240
    thumbnail quality: 70
    latest:
    immediate 1
    AF on capture: 0
    Zero shutter lag: 0
Running without preview window
Opening camera...
Acquired camera /base/axi/pcie@120000/rp1/i2c@88000/imx283@1a
Configuring still capture...
Mode selection for 5472:3648:12:P
    SRGGB10_CSI2P,5568x3094/0 - Score: 2244.35
    SRGGB10_CSI2P,5568x3664/0 - Score: 1035.37
    SRGGB12_CSI2P,2784x1828/0 - Score: 9024.62
    SRGGB12_CSI2P,5568x3664/0 - Score: 35.369
Stream configuration adjusted
[1:17:47.387747938] [2523]  INFO Camera camera.cpp:1183 configuring streams: (0) 5472x3648-YUV420 (1) 5568x3664-RGGB16_PISP_COMP1
[1:17:47.388182254] [2524]  INFO RPI pisp.cpp:1405 Sensor: /base/axi/pcie@120000/rp1/i2c@88000/imx283@1a - Selected sensor format: 5568x3664-SRGGB12_1X12 - Selected CFE format: 5568x3664-PC1R
[1:17:47.388789516] [2524]  INFO IPARPI ipa_base.cpp:555 Adjusting mode minimum line length from 12.32us to 14.65us because of ISP constraints.
Camera streams configured
Available controls:
    Sharpness : [0.000000..16.000000]
    AwbEnable : [false..true]
    Contrast : [0.000000..32.000000]
    Saturation : [0.000000..32.000000]
    Brightness : [-1.000000..1.000000]
    AeFlickerPeriod : [100..1000000]
    HdrMode : [0..4]
    ExposureValue : [-8.000000..8.000000]
    ColourGains : [0.000000..32.000000]
    StatsOutputEnable : [false..true]
    ScalerCrop : [(0, 0)/337x228..(0, 0)/5472x3648]
    ExposureTime : [9039794..0]
    AeEnable : [false..true]
    NoiseReductionMode : [0..4]
    AeConstraintMode : [0..3]
    FrameDurationLimits : [55577..164960255]
    AnalogueGain : [1.000000..22.505495]
    AeFlickerMode : [0..1]
    AwbMode : [0..7]
    AeMeteringMode : [0..3]
    AeExposureMode : [0..3]
Buffers allocated and mapped
Still capture setup complete
Requests created
Camera started!
Camera stopped!
Still capture image received
Exposure time: 9999083
Ag 1 Dg 1.00009 Total 1.00009
Thumbnail dimensions are 320 x 240
Thumbnail size 23752
JPEG size is 12603403
EXIF data len 298
Saved image 5472 x 3648 to file test_data/testR.raw
Closing RPiCam application(frames displayed 0, dropped 0)
Camera stopped!
Tearing down requests, buffers and configuration
Camera closed
jackblack@raspberrypi:~/star_recognizer3 $ rpicam-still -o test_data/testR.raw --timeout 1 --tuning-file imx283.json --analoggain 1 --awbgains 1.0,3.5 --saturation 1 --contrast 1 --sharpness 1 --brightness 0  --nopreview --autofocus-mode manual --immediate --gain 1 --shutter 10000000  --camera 1 -v
[1:18:18.032780325] [2533]  INFO Camera camera_manager.cpp:284 libcamera v0.0.0+4579-80845ad5
[1:18:18.035754131] [2534]  INFO RPI pisp.cpp:662 libpisp version v1.0.4 6e3a53d137f4 07-03-2024 (09:04:18)
[1:18:18.038878382] [2534]  WARN CameraSensorProperties camera_sensor_properties.cpp:274 No static properties available for 'imx283'
[1:18:18.038904104] [2534]  WARN CameraSensorProperties camera_sensor_properties.cpp:276 Please consider updating the camera sensor properties database
[1:18:18.045993405] [2534]  WARN RPiAlsc alsc.cpp:170 no luminance table - assume unity everywhere
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
will127534, 2025-06-06:
Which driver are you using for Arducam module?

almowery, 2025-06-06:
The only driver I have is the driver u created.  Arducam never furnished a driver for raspberry pi, they sold it for the Jetson.  They are not selling the module separate anymore they are selling a Pivistation 5 which has a preinstalled OS and I assume drivers but is sold as a video camera.

almowery, 2025-06-06:
This is the rpicam-apps thread about the helper files and the extra frame.

https://github.com/raspberrypi/rpicam-apps/issues/524

will127534, 2025-06-06:
Ok so, to summarize your question:
> they seemed to work fine except I could never get them to drop
> exposure time down to 10sec. even starts first frame at 40sec. then next frame is 20sec.

You want to capture one frame immediately (10s exposure -> 10s of total time spend on capturing), but you can't do that with 2 camera module attach?

almowery, 2025-06-06:
uc-769 discontinued, interesting that it works at all.

I found this page
https://www.arducam.com/arducam-20mp-imx283-camera-module-with-m12-mount-lens-and-adapter-board-for-depthai.html

https://github.com/luxonis/depthai-python/issues/725

I originally purchased through Uctronics
Arducam 20MP IMX283 Camera module with C mount lens for DepthAI OAK
SKU: B0301

Mine has a ir cut filter gizmo to move filter in/out.  You don't even see those on their advertisements.

I know your driver works on them, but obviously not perfectly.  i just had such a trouble getting two from tindie.  I own one of yours from early on you development.  I saw someone was able to manufacture some using your files.  Is that really possible?  Possible to get the imx283? Thanks for fast responses.  AL

almowery, 2025-06-06:
https://www.fabtolab.com/arducam-b0301-20mp-imx283-camera-module-c-mount-lens-adapter-board-depthai-oak

almowery, 2025-06-06:
Your hint to check to see if the OSC is present worked out well. Thank You.  The OSC is 12.000Mhz

Ok so I found the method to stop the extra frame using the line in rpi-apps.yaml.  I determined the arducam does have the osc hooked up and the osc is 12.000Mhz and not the 24.00Mhz on your board.  That would explain the time that it takes for an exposure is 2x.  I can change the osc on the arducam boards but I thought I could test it with a software recompile, first.  I see in your imx283 driver that each of the typical clock speeds are present in an array.  I can't figure and the clk_get_rate() function get's the speed set by the system.  I just don't known where this comes from and how to change the setting so your driver loads the 12mhz values into the imx283 registers instead of the 24Mhz values.

Very close.  Thank you.  AL

will127534, 2025-06-07:
So I guess that is why, the PLL is setup as if it is a 24Mhz clock, I'll recommend you swap it to 24Mhz to align both of your camera. Or.... you just /2 on OAK camera module and have the same result I guess. (Not sure if that will impact other stuff but given that we are running IMX283 half the speed it should be fine)

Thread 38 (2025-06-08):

Not booting with Pi 5

malcolmjay, 2025-06-08:
Hi Will,

I have the camera board connected into the cam 1 slot on the pi 5 and followed your fpc instructions. The pi doesn’t boot whenever I have the camera connected.  I’ve installed all of the drivers - any ideas on how to troubleshoot this?

Thank you,

Malcolm

malcolmjay, 2025-06-08:
Yes I’m using a single sided FPC - attached are photos.

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

will127534, 2025-06-08:
So.. no, this is double side FPC where you have contact on the different side.

This is the single side FPC:
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

malcolmjay, 2025-06-08:
Thank you! I will buy the correct cable.

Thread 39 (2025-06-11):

Questions about TMP117 and ICM42688-P

Alistair-cloud, 2025-06-11:
Hi Wil,
I noticed that this sensor has TMP117 and ICM42688-P on it, how can I get their data in real time

will127534, 2025-06-13:
For ICM42688-P: https://github.com/will127534/OneInchEye/wiki/Reading-IMU-data-with-Video-frames
For TMP117, you can use Adafruit's library: https://learn.adafruit.com/adafruit-tmp117-high-accuracy-i2c-temperature-monitor/overview

Closed 2025-06-19.

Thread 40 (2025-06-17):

Questions about IR cut filters

Alistair-cloud, 2025-06-17:
I bought an IR cut filter that can be switched, and I wanted to ask if this board has a switching interface like the IMX585

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

eva-00100, 2025-06-17:
I solved the problem with a motor driver board from an L9110S

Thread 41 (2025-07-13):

About IMU ICM42688-P

eva-00100, 2025-07-13:
I connected to the Raspberry Pi cam0 as required and adjusted the imu.json "i2c-6" but the terminal showed the following message

pi@CAMERA:~ $ rpicam-vid -t 0 --post-process-file imu.json
[0:18:18.753879439] [14873]  INFO Camera camera_manager.cpp:326 libcamera v0.0.0+5532-9d0cdfe5-dirty (2025-06-25T22:35:37CST)
[0:18:18.754629477] [14884]  INFO RPI pisp.cpp:720 libpisp version v1.2.0 50426319aa1a 25-06-2025 (22:35:37)
[0:18:18.764555493] [14884]  WARN RPiAlsc alsc.cpp:171 no luminance table - assume unity everywhere
[0:18:18.765535347] [14884]  INFO RPI pisp.cpp:1179 Registered camera /base/axi/pcie@1000120000/rp1/i2c@88000/imx283@1a to CFE device /dev/media0 and ISP device /dev/media2 using PiSP variant BCM2712_C0
Preview window unavailable
No post processing stage found for "imu_sync"
Mode selection for 640:480:12:P
    SRGGB10_CSI2P,5568x3094/0 - Score: 3060.35
    SRGGB10_CSI2P,5568x3664/0 - Score: 3097.87
    SRGGB12_CSI2P,2784x1828/0 - Score: 944.116
    SRGGB12_CSI2P,5568x3664/0 - Score: 2097.87
Stream configuration adjusted
[0:18:18.767234664] [14873]  INFO Camera camera.cpp:1205 configuring streams: (0) 640x480-YUV420 (1) 2784x1828-RGGB_PISP_COMP1
[0:18:18.767323275] [14884]  INFO RPI pisp.cpp:1483 Sensor: /base/axi/pcie@1000120000/rp1/i2c@88000/imx283@1a - Selected sensor format: 2784x1828-SRGGB12_1X12 - Selected CFE format: 2784x1828-PC1R
[libx264 @ 0x555658723000] using cpu capabilities: ARMv8 NEON
[libx264 @ 0x555658723000] profile High, level 3.0, 4:2:0, 8-bit
Output #0, h264, to '':
  Stream #0:0: Video: h264, yuv420p(tv, smpte170m/smpte170m/bt709), 640x480, q=2-31, 30 fps, 30 tbr, 1000k tbn
#0 (0.00 fps) exp 33309.00 ag 8.00 dg 1.00
#1 (30.00 fps) exp 33309.00 ag 8.00 dg 1.00
#2 (30.00 fps) exp 33309.00 ag 8.00 dg 1.00
#3 (30.00 fps) exp 33309.00 ag 8.00 dg 1.00
#4 (30.00 fps) exp 33309.00 ag 8.00 dg 1.00
#5 (30.00 fps) exp 33309.00 ag 8.00 dg 1.00
#6 (30.00 fps) exp 33309.00 ag 8.00 dg 1.00
#7 (30.00 fps) exp 33309.00 ag 8.00 dg 1.00
#8 (30.01 fps) exp 33309.00 ag 8.00 dg 1.00
#9 (30.00 fps) exp 33309.00 ag 8.00 dg 1.00
#10 (30.00 fps) exp 33309.00 ag 8.00 dg 1.00
#11 (30.00 fps) exp 33309.00 ag 8.00 dg 1.00
#12 (30.00 fps) exp 33309.00 ag 8.00 dg 1.00
#13 (30.00 fps) exp 33309.00 ag 8.00 dg 1.00
#14 (30.00 fps) exp 33309.00 ag 8.00 dg 1.00
#15 (30.00 fps) exp 33309.00 ag 8.00 dg 1.00
#16 (30.00 fps) exp 33309.00 ag 8.00 dg 1.00
^CReceived signal 2
[libx264 @ 0x555658723000] frame I:1     Avg QP: 9.98  size:  2896
[libx264 @ 0x555658723000] frame P:8     Avg QP:10.69  size:  1038
[libx264 @ 0x555658723000] frame B:8     Avg QP:12.80  size:   416
[libx264 @ 0x555658723000] consecutive B-frames:  5.9% 94.1%
[libx264 @ 0x555658723000] mb I  I16..4: 99.9%  0.0%  0.1%
[libx264 @ 0x555658723000] mb P  I16..4: 86.8%  0.0%  0.0%  P16..4:  1.9%  0.0%  0.0%  0.0%  0.0%    skip:11.3%
[libx264 @ 0x555658723000] mb B  I16..4:  0.0%  0.0%  0.0%  B16..8:  0.1%  0.0%  0.0%  direct:24.6%  skip:75.3%  L0: 0.0% L1:100.0% BI: 0.0%
[libx264 @ 0x555658723000] 8x8 transform intra:0.0%
[libx264 @ 0x555658723000] coded y,uvDC,uvAC intra: 0.1% 38.6% 24.1% inter: 0.0% 23.5% 0.2%
[libx264 @ 0x555658723000] i16 v,h,dc,p: 100%  0%  0%  0%
[libx264 @ 0x555658723000] i4 v,h,dc,ddl,ddr,vr,hd,vl,hu:  0%  0% 100%  0%  0%  0%  0%  0%  0%
[libx264 @ 0x555658723000] i8c dc,h,v,p: 65% 21% 12%  1%
[libx264 @ 0x555658723000] kb/s:205.22

will127534, 2025-07-14:
No post processing stage found for "imu_sync"

Do you have the latest rpicam-apps from my fork?

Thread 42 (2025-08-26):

More stock to buy/borrow?

Babyyoda777, 2025-08-26:
Hi, I’m working on a custom CM5 carrier PCB here at https://github.com/azlan-works/Argo and was looking to use the OneInchEye but unfortunately it’s completely out of stock. Is there a timeline for when there will be any available to get @will127534 or would it be possible to borrow one for testing in the meantime (would really appreciate any help!).

My carrier pcb is tiny and includes built in battery management and I’m trying to optimise for portable photography. This is the best all round native CSI board I’ve seen and can’t really source the sensor myself either. Would love it if we could work on this!

will127534, 2025-08-27:
Neet, I do have a few for my own projects so can definitely send one to you, send me a message to will [at] willwhang.com

Babyyoda777, 2025-08-29:
Hey @will127534 just had a side thing to add, came across this promising looking successor to the IMX283:

https://www.ovt.com/wp-content/uploads/2025/04/OV50X50-PB-v1.0-WEB.pdf

It says it's currently in sampling and then production in Q3 2025 but at 50MP and 1" it also supports pixel binning to 12.5MP which seems cool.

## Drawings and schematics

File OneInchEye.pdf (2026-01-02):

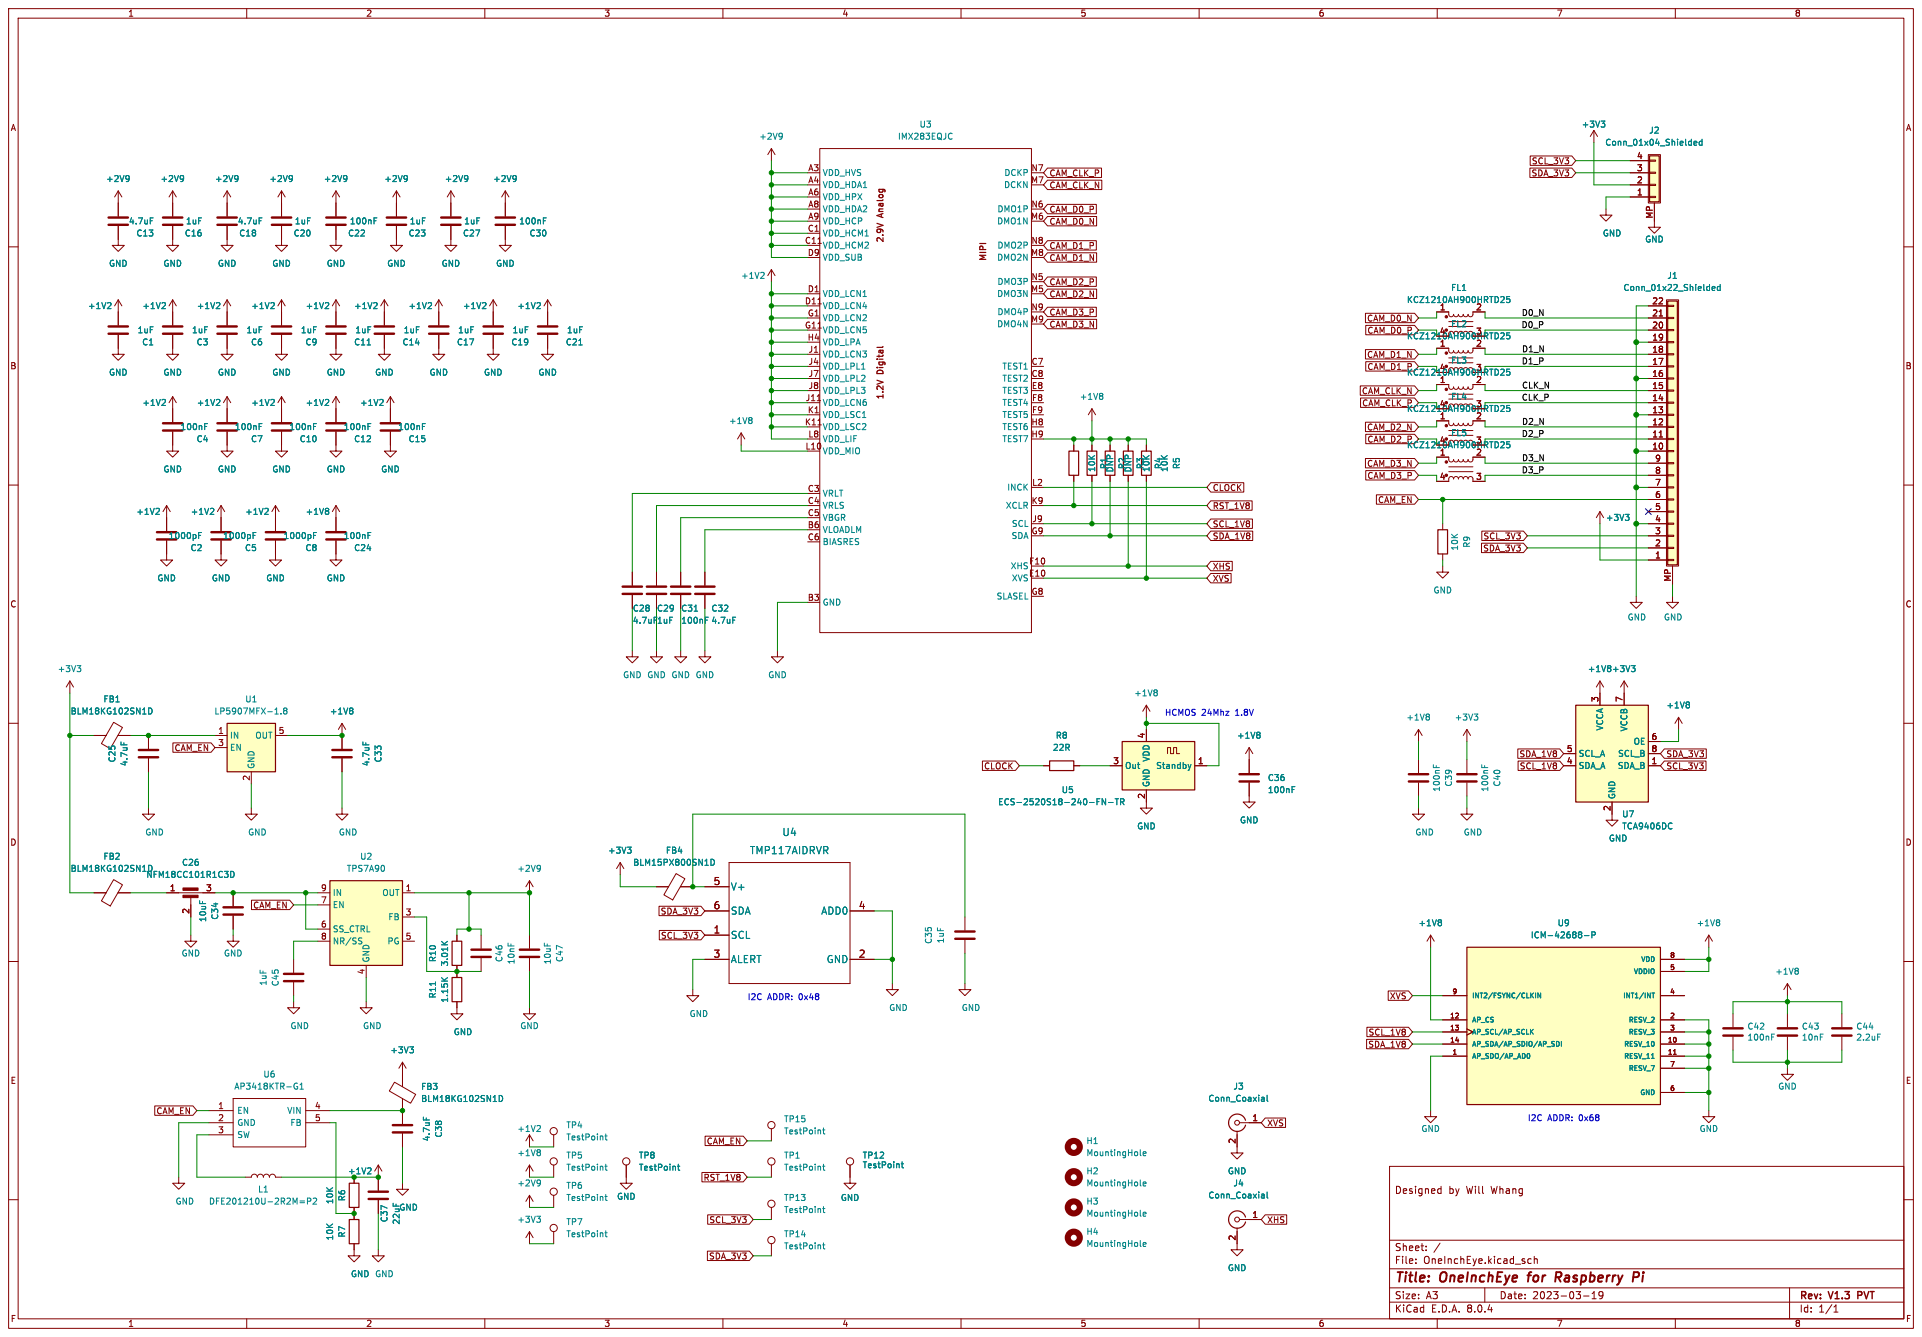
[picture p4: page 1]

4 PG 5 SS_CTRL 6 EN 7 NR/SS 8

J3 Conn_Coaxial
H3 MountingHole H1 MountingHole H4 MountingHole H2 MountingHole

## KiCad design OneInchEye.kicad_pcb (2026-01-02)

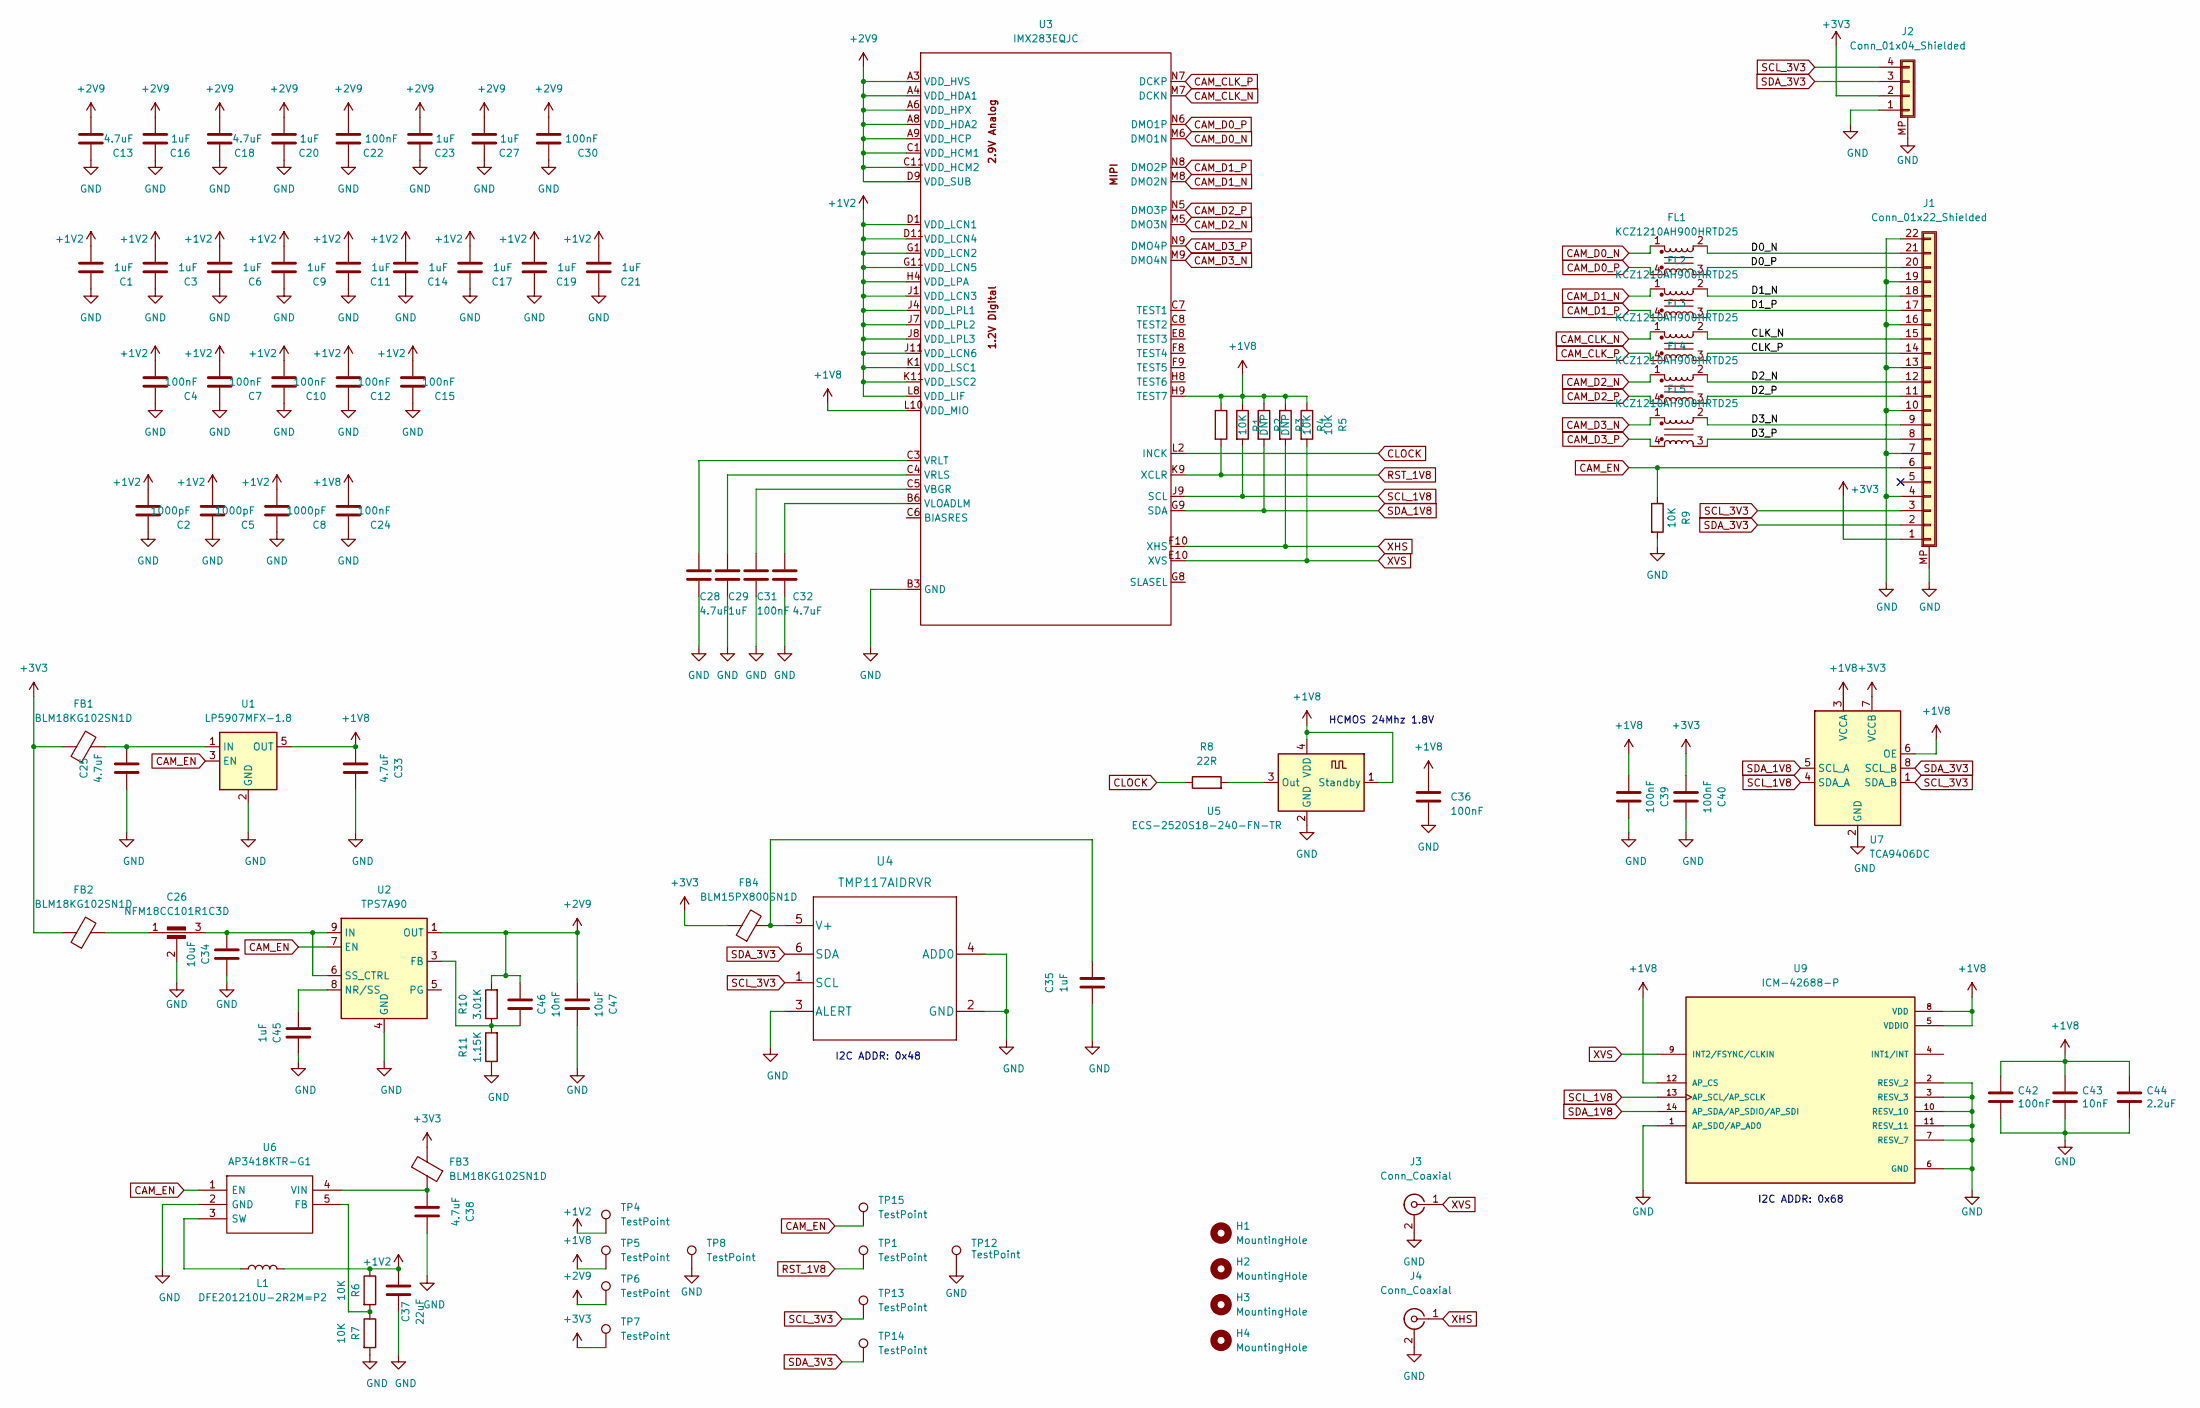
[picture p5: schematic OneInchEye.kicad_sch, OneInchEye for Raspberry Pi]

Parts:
C1, C3, C6, C9, C11, C14, C16, C17, C19, C20, C21, C23, C27, C29, C35, C45: 1uF; C_0402_1005Metric
C2, C5, C8: 1000pF; C_0402_1005Metric
C4, C7, C10, C12, C15, C22, C24, C30, C31, C36, C39, C40, C42: 100nF; C_0402_1005Metric
C13, C18, C25, C28, C32, C33, C38: 4.7uF; C_0603_1608Metric
C26: NFM18CC101R1C3D
C34, C47: 10uF; C_0603_1608Metric
C37: 22uF; C_0603_1608Metric
C43, C46: 10nF; C_0402_1005Metric
C44: 2.2uF; C_0402_1005Metric
FB1, FB2, FB3: BLM18KG102SN1D; L_0603_1608Metric
FB4: BLM15PX800SN1D; L_0402_1005Metric
FL1, FL2, FL3, FL4, FL5: KCZ1210AH900HRTD25; DLP11SA350HL2B
H1, H2, H3, H4: MountingHole; MountingHole_2.2mm_M2
J1: Conn_01x22_Shielded; TF3822S05SV830
J2: Conn_01x04_Shielded; JST_SH_BM04B-SRSS-TB_1x04-1MP_P1.00mm_Vertical
J3, J4: Conn_Coaxial; U.FL_Hirose_U.FL-R-SMT-1_Vertical
L1: DFE201210U-2R2M=P2; L_0805_2012Metric
R1, R4, R5, R6, R7, R9: 10K; R_0402_1005Metric
R2, R3: DNP; R_0402_1005Metric
R8: 22R; R_0402_1005Metric
R10: 3.01K; R_0402_1005Metric
R11: 1.15K; R_0402_1005Metric
TP1, TP4, TP5, TP6, TP7, TP8, TP12, TP13, TP14, TP15: TestPoint; TestPoint_Pad_D1.0mm
U1: LP5907MFX-1.8; SOT-23-5
U2: TPS7A90; Texas_S-PDSO-N10_EP1.2x2mm
U3: IMX283EQJC; IMX283
U4: TMP117AIDRVR
U5: ECS-2520S18-240-FN-TR; Oscillator_SMD_Abracon_ASDMB-4Pin_2.5x2.0mm
U6: AP3418KTR-G1; SOT-23-5; Mouser Part Number 621-AP3418KTR-G1
U7: TCA9406DC; TCA9406DCUR
U9: ICM-42688-P; IIM42352; PARTREV 1.2

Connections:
+1V2: C1.2, C2.2, C3.2, C4.2, C5.2, C6.2, C7.2, C8.2, C9.2, C10.2, C11.2, C12.2, C14.2, C15.2, C17.2, C19.2, C21.2, C37.2, L1.2, R6.1, TP4.1, U3.D1 (VDD_LCN1), U3.D11 (VDD_LCN4), U3.G1 (VDD_LCN2), U3.G11 (VDD_LCN5), U3.H4 (VDD_LPA), U3.J1 (VDD_LCN3), U3.J4 (VDD_LPL1), U3.J7 (VDD_LPL2), U3.J8 (VDD_LPL3), U3.J11 (VDD_LCN6), U3.K1 (VDD_LSC1), U3.K11 (VDD_LSC2), U3.L8 (VDD_LIF)
+1V8: C24.2, C33.1, C36.1, C39.1, C42.1, C43.1, C44.1, R1.1, R2.1, R3.1, R4.1, R5.1, TP5.1, U1.5 (OUT), U3.H9 (TEST7), U3.L10 (VDD_MIO), U5.1 (Standby), U5.4 (VDD), U7.3 (VCCA), U7.6 (OE), U9.5 (VDDIO), U9.8 (VDD), U9.12 (AP_CS)
+2V9: C13.2, C16.2, C18.2, C20.2, C22.2, C23.2, C27.2, C30.2, C46.2, C47.1, R10.2, TP6.1, U2.1 (OUT), U2.2 (OUT), U3.A3 (VDD_HVS), U3.A4 (VDD_HDA1), U3.A6 (VDD_HPX), U3.A8 (VDD_HDA2), U3.A9 (VDD_HCP), U3.C1 (VDD_HCM1), U3.C11 (VDD_HCM2), U3.D9 (VDD_SUB)
+3V3: C40.1, FB1.1, FB2.1, FB3.2, FB4.1, J1.1, J2.2, TP7.1, U7.7 (VCCB)
/CLK_N: FL3.2, J1.15
/CLK_P: FL3.3, J1.14
/D0_N: FL1.2, J1.21
/D0_P: FL1.3, J1.20
/D1_N: FL2.2, J1.18
/D1_P: FL2.3, J1.17
/D2_N: FL4.2, J1.12
/D2_P: FL4.3, J1.11
/D3_N: FL5.2, J1.9
/D3_P: FL5.3, J1.8
CAM_CLK_N: FL3.1, U3.M7 (DCKN)
CAM_CLK_P: FL3.4, U3.N7 (DCKP)
CAM_D0_N: FL1.1, U3.M6 (DMO1N)
CAM_D0_P: FL1.4, U3.N6 (DMO1P)
CAM_D1_N: FL2.1, U3.M8 (DMO2N)
CAM_D1_P: FL2.4, U3.N8 (DMO2P)
CAM_D2_N: FL4.1, U3.M5 (DMO3N)
CAM_D2_P: FL4.4, U3.N5 (DMO3P)
CAM_D3_N: FL5.1, U3.M9 (DMO4N)
CAM_D3_P: FL5.4, U3.N9 (DMO4P)
CAM_EN: J1.6, R9.1, TP15.1, U1.3 (EN), U2.7 (EN), U6.1 (EN)
CLOCK: R8.1, U3.L2 (INCK)
GND: C1.1, C2.1, C3.1, C4.1, C5.1, C6.1, C7.1, C8.1, C9.1, C10.1, C11.1, C12.1, C13.1, C14.1, C15.1, C16.1, C17.1, C18.1, C19.1, C20.1, C21.1, C22.1, C23.1, C24.1, C25.1, C26.2, C27.1, C28.2, C29.2, C30.1, C31.2, C32.2, C33.2, C34.2, C35.1, C36.2, C37.1, C38.2, C39.2, C40.2, C42.2, C43.2, C44.2, C45.2, C47.2, J1.4, J1.7, J1.10, J1.13, J1.16, J1.19, J1.22, J1.MP (Shield), J2.1, J2.MP (Shield), J3.2 (Ext), J4.2 (Ext), R7.2, R9.2, R11.1, TP8.1, TP12.1, U1.2 (GND), U2.4 (GND), U2.11 (GND), U3.B3 (GND), U3.B4 (GND2), U3.B5 (GND3), U3.B7 (GND4), U3.B8 (GND5), U3.B9 (GND6), U3.C2 (GND8), U3.C10 (GND7), U3.D2 (GND9), U3.D10 (GND10), U3.G2 (GND11), U3.G10 (GND12), U3.H2 (GND13), U3.H3 (GND14), U3.H10 (GND15), U3.J2 (GND16), U3.J10 (GND17), U3.K2 (GND18), U3.K4 (GND19), U3.K7 (GND20), U3.K8 (GND21), U3.K10 (GND22), U3.L7 (GND23), U3.L9 (GND24), U3.N4 (GND25), U4.2 (GND), U4.3 (ALERT), U4.4 (ADD0), U5.2 (GND), U6.2 (GND), U7.2 (GND), U9.1 (AP_SDO/AP_AD0), U9.2 (RESV_2), U9.3 (RESV_3), U9.6 (GND), U9.7 (RESV_7), U9.10 (RESV_10), U9.11 (RESV_11)
unnamed: C26.1, FB2.2
unnamed: C25.2, FB1.2, U1.1 (IN)
unnamed: C46.1, R10.1, R11.2, U2.3 (FB)
unnamed: C45.1, U2.8 (NR/SS)
unnamed: C26.3, C34.1, U2.6 (SS_CTRL), U2.9 (IN), U2.10 (IN)
unnamed: C31.1, U3.C5 (VBGR)
unnamed: C32.1, U3.B6 (VLOADLM)
unnamed: C29.1, U3.C4 (VRLS)
unnamed: C28.1, U3.C3 (VRLT)
unnamed: C35.2, FB4.2, U4.5 (V+)
unnamed: R8.2, U5.3 (Out)
unnamed: R6.2, R7.1, U6.5 (FB)
unnamed: L1.1, U6.3 (SW)
unnamed: C38.1, FB3.1, U6.4 (VIN)
RST_1V8: R1.2, TP1.1, U3.K9 (XCLR)
SCL_1V8: R2.2, U3.J9 (SCL), U7.4 (SDA_A), U9.13 (AP_SCL/AP_SCLK)
SCL_3V3: J1.3, J2.4, TP13.1, U4.1 (SCL), U7.1 (SDA_B)
SDA_1V8: R3.2, U3.G9 (SDA), U7.5 (SCL_A), U9.14 (AP_SDA/AP_SDIO/AP_SDI)
SDA_3V3: J1.2, J2.3, TP14.1, U4.6 (SDA), U7.8 (SCL_B)
XHS: J4.1 (In), R4.2, U3.F10 (XHS)
XVS: J3.1 (In), R5.2, U3.E10 (XVS), U9.9 (INT2/FSYNC/CLKIN)

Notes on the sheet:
I2C ADDR: 0x48
I2C ADDR: 0x68
HCMOS 24Mhz 1.8V

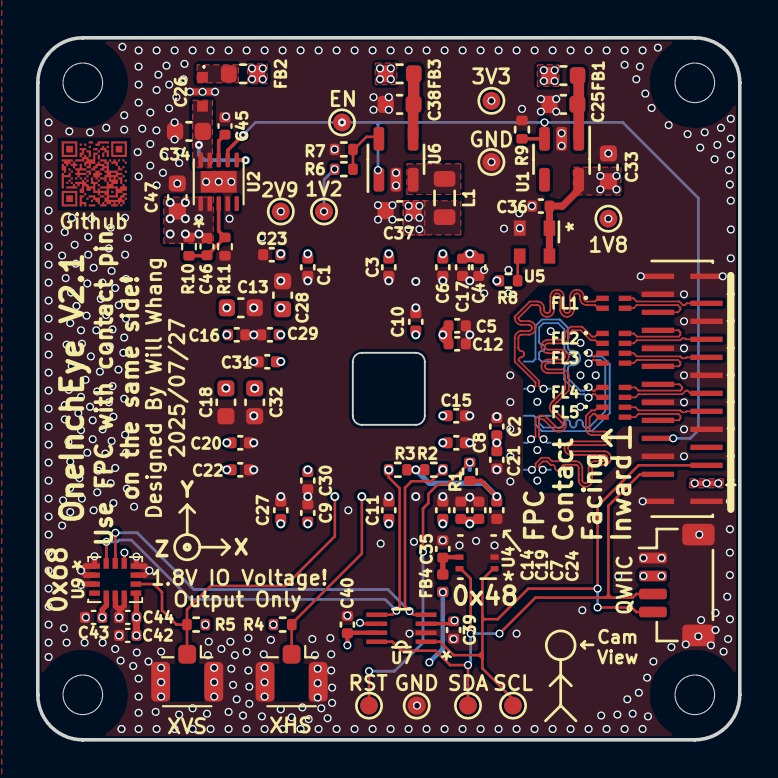
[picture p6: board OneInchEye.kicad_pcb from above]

Board: 4 copper layers, 39.0 x 39.0 mm, 93 parts (1 on the bottom side), 48 nets.

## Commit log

2023-03-20 init v1.3
    [OneInchEye-B_Cu.gbr, OneInchEye-B_Mask.gbr, OneInchEye-B_Paste.gbr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]
2023-04-09 Adding correct BOM
    [CPL_JLCSMT.xlsx]
2023-04-09 Update SOT-32 NMOS part number
    [BOM_JLCSMT.csv]
2024-02-17 Update to v1.4
    [BOM_JLCSMT.csv, BOM_JLCSMT.xlsx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]
2024-10-06 Adding IMU and update board outline to 39mm square
    [BOM_JLCSMT.xlsx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]
